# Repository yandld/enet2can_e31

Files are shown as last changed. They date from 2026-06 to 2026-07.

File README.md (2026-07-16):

# NXP Application Code Hub
[](https://www.nxp.com)

## MCXE31B Ethernet-to-Six-CAN FD Bridge
[中文说明](README.zh-CN.md)

This project implements an Ethernet-to-six-CAN FD bridge based on the NXP
MCXE31B. A Linux host loads the `eth2can.ko` driver and sees six standard
SocketCAN interfaces, `eth2can0` through `eth2can5`. Existing SocketCAN tools
and applications can then send and receive CAN FD frames through the MCXE31B
gateway.

The basic architecture is outlined below:

MCXE31B Ethernet-to-six-CAN FD bridge system overview

* **Linux SocketCAN driver:** `eth2can.ko` binds to one Ethernet interface,
  exchanges raw E2CF Layer-2 frames with the gateway, and exposes six CAN FD
  channels as SocketCAN devices.
* **MCXE31B gateway firmware:** The bare-metal firmware receives E2CF Ethernet
  frames, forwards CAN FD traffic through FlexCAN0..FlexCAN5, reports status,
  and supervises the heartbeat between Linux and the gateway.
* **Customer validation tool:** `canperf` provides latency and bidirectional
  maximum sustainable bandwidth checks for the default six-channel harness.

#### Boards: MCXE31B gateway board
#### Categories: Tools
#### Peripherals: CAN FD, Ethernet
#### Toolchains: MDK, GCC

## Table of Contents
1. [Software](#step1)
2. [Hardware](#step2)
3. [Setup](#step3)
4. [Results](#step4)
5. [FAQs](#step5)
6. [Support](#step6)
7. [Release Notes](#step7)

## 1. Software

This repository contains the MCXE31B firmware, Linux driver, validation tool,
and design notes required to bring up the bridge.

Project classification and description:

| Project | Path | Description |
|---|---|---|
| MCXE31B firmware | `source/`, `board/` | Bare-metal bridge firmware using ENET_QOS raw Layer-2 Ethernet and FlexCAN0..FlexCAN5 |
| Linux driver | `linux/` | Out-of-tree SocketCAN driver, installer script, and driver tests |
| canperf | `linux/can_testcase/` | Customer latency and bidirectional bandwidth validation tool |
| Design notes | `docs/*.md` | E2CF protocol, Linux driver, firmware, and EQOS TX design documentation |

Default bridge configuration:

| Item | Default |
|---|---|
| Host API | SocketCAN devices `eth2can0` through `eth2can5` |
| Ethernet transport | Raw Layer-2 E2CF, EtherType `0x88B5` |
| Deployment VLAN | VID `100`; untagged frames are allowed during bring-up |
| CAN FD nominal bitrate | 1 Mbit/s |
| CAN FD data bitrate | 5 Mbit/s |
| CAN FD BRS | Enabled |
| TX window | 16 echo/TXC slots per CAN channel |
| MCU-to-Linux aggregation | Record-count based or 50 us timer |
| Heartbeat supervision | 100 ms period, 500 ms timeout |

### Software Protocol

E2CF is a little-endian raw Ethernet protocol shared by the Linux driver and
the MCXE31B firmware. The frame EtherType is `0x88B5`. The protocol carries
CAN frame data, CAN transmit-completion status, configuration transactions,
events, time mapping, heartbeat, and statistics.

Message types used by this delivery:

| Type | Direction | Purpose |
|---|---|---|
| DATA | Both directions | CAN frames or Linux transmit requests |
| TXC | MCXE31B to Linux | CAN transmit completion and echo-slot release |
| EVT | MCXE31B to Linux | CAN state and error events |
| CFG_REQ / CFG_RSP | Linux to MCXE31B / MCXE31B to Linux | Channel configuration and status transactions |
| TIME | MCXE31B to Linux | Gateway time mapping |
| HB | Both directions | Peer discovery and heartbeat supervision |
| STATS | MCXE31B to Linux | Gateway counters for diagnostics and validation |

E2CF data and management paths between Linux and the MCXE31B gateway

For protocol details, see
[`docs/e2cf-protocol-spec.md`](docs/e2cf-protocol-spec.md).

## 2. Hardware

Use one MCXE31B gateway board, one Linux host connected to the gateway Ethernet
port, and six external CAN FD transceivers.

Default CAN FD harness:

```text
eth2can0 <-> eth2can4
eth2can1 <-> eth2can2
eth2can3 <-> eth2can5
```

Each pair is one independent CAN FD bus. Use 120 ohm termination at both ends,
keep CANH/CANL polarity correct, power the transceivers, and share ground with
the gateway board.

### Pin Table

The table below lists the primary CAN, Ethernet, and debug UART connections
used by this project.

| Function | MCU signal | Package pin | Description |
|---|---|---:|---|
| CAN0 TX/RX | PTA7 / PTA6 | 100 / 102 | CAN0 transceiver TXD/RXD |
| CAN1 TX/RX | PTA11 / PTA12 | 160 / 159 | CAN1 transceiver TXD/RXD |
| CAN2 TX/RX | PTE24 / PTE25 | 157 / 158 | CAN2 transceiver TXD/RXD |
| CAN3 TX/RX | PTC28 / PTC29 | 96 / 99 | CAN3 transceiver TXD/RXD |
| CAN4 TX/RX | PTC30 / PTC31 | 101 / 103 | CAN4 transceiver TXD/RXD |
| CAN5 TX/RX | PTC27 / PTC26 | 93 / 91 | CAN5 transceiver TXD/RXD |
| RMII MDIO/MDC | PTB4 / PTB5 | 48 / 47 | Ethernet PHY management |
| RMII data/control | PTC2, PTD7, PTD12, PTC17, PTC1, PTC0, PTD11 | 50, 51, 54, 65, 61, 62, 55 | Ethernet RMII signals |
| PHY reset | PTC3 | 49 | Ethernet PHY reset GPIO |
| Debug UART RX/TX | PTE3 / PTE14 | 27 / 26 | Debug console |

Status LED behavior:

| LED | State | Meaning |
|---|---|---|
| SYS | About 1 Hz blinking | Firmware superloop is running |
| NET | Solid on | Ethernet/E2CF link is ready |
| CAN | Blinking | CAN RX/TX traffic is active |
| CAN | Solid on | At least one active CAN bus is error-passive or bus-off |

## 3. Setup

Before getting started, prepare a Linux host with SocketCAN support, matching
kernel headers or a matching kernel build tree, and common tools such as
`make`, `gcc`, `kmod`, `iproute2`, and `can-utils`.

### 3.1 Step 1

Program or confirm the MCXE31B gateway firmware. If the board is already
programmed, power it up. To build the firmware yourself, open
`e2cf_mcxe31.uvprojx` in Keil MDK, build the MCXE31B target, and program the
board with your normal MCXE31B/SWD flow.

### 3.2 Step 2

Connect the Linux host to the MCXE31B Ethernet port. Connect the default CAN FD
harness:

```text
eth2can0 <-> eth2can4
eth2can1 <-> eth2can2
eth2can3 <-> eth2can5
```

### 3.3 Step 3

Build and load the Linux driver from the repository root:

```bash
$ sh linux/scripts/install_driver.sh
```

Common variants:

```bash
$ sh linux/scripts/install_driver.sh --ifname eth1 --vid 100
$ KDIR=/path/to/kernel/build sh linux/scripts/install_driver.sh --ifname end0
$ sh linux/scripts/install_driver.sh --dry-run
$ sh linux/scripts/install_driver.sh --require-gateway
```

The installer builds `eth2can.ko`, loads it for the current boot, waits for the
gateway heartbeat, and configures `eth2can0..5` for CAN FD 1M/5M. It does not
install DKMS, systemd units, or persistent autoload configuration.

### 3.4 Step 4

Confirm the SocketCAN devices:

```bash
$ ip -details link show type can
```

Six interfaces, `eth2can0` through `eth2can5`, should be present.

### 3.5 Step 5

Run a basic CAN FD transmit check:

```bash
$ candump eth2can4 &
$ cansend eth2can0 123##3001122334455667788
```

If `eth2can4` receives the frame, the Linux driver, Ethernet transport,
MCXE31B firmware, and at least one physical CAN FD bus are working.

### 3.6 Step 6

Build and run the customer validation tool:

```bash
$ cd linux/can_testcase
$ make
$ ./canperf latency --count 10000
$ ./canperf bandwidth
```

## 4. Results

The expected first-level result is that all six SocketCAN devices are created,
the default harness passes basic `candump` / `cansend` traffic, and `canperf`
prints final `RESULT` and `EVIDENCE` lines.

Example result lines:

```bash
RESULT latency: PASS, zero_loss=yes, ...
EVIDENCE latency: ..., counters=clean
RESULT bandwidth: PASS, zero_loss=yes, MSR=... fps/pair, ...
EVIDENCE bandwidth: ..., counters=clean
```

For acceptance, use the final `RESULT` line as the customer conclusion. `PASS`
means zero-loss for that run. Latency reports p50, p99, and p99.9. Bandwidth
reports MSR, the maximum sustainable rate. `counters=clean` means relevant
driver and gateway loss, overflow, reject, and send-failure counters did not
increase during the confirmation round.

This repository does not define fixed p99 or MSR pass/fail limits. Thresholds
must be agreed for the target harness, host, and system load.

## 5. FAQs

* Why does the Linux host see six `eth2canN` devices instead of one raw
  Ethernet device?

  The Linux driver presents the gateway as standard SocketCAN interfaces so
  existing CAN applications can run without a custom user-space API.

* Does the MCXE31B firmware use TCP/IP or lwIP?

  No. The firmware uses ENET_QOS raw Layer-2 Ethernet and the E2CF protocol.

* Are fixed p99 latency or MSR bandwidth limits defined by this repository?

  No. The tools report measured latency, MSR, and clean/dirty counters. Final
  limits depend on the harness, Linux host, and system load.

* Is this repository an open-source release?

  No. It is not published under an open-source license in its current form.
  See the distribution notice below.

## 6. Support

#### Project Metadata
<!----- Boards ----->


<!----- Categories ----->


<!----- Peripherals ----->



<!----- Toolchains ----->



Questions regarding the content or correctness of this project can be entered
as Issues within this GitHub repository.

> **Warning**: For general technical questions about NXP microcontrollers,
> use the [NXP Community Forum](https://community.nxp.com/).






Distribution notice: this repository is not published under an open-source
license in its current form. Copying, redistribution, product use, or
publication outside the authorized project scope requires written permission
from the repository owner. Preserve all SPDX notices in source files.

## 7. Release Notes

| Version | Description / Update | Date |
|:---:|---|---:|
| 1.0 | Initial release for MCXE31B Ethernet-to-six-CAN FD bridge | July 4<sup>th</sup> 2026 |

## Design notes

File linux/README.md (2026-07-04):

# eth2can Linux Driver Installation and Test

[中文说明](README.zh-CN.md)

`eth2can.ko` exposes the six MCXE31B CAN FD channels as standard SocketCAN
devices, `eth2can0` through `eth2can5`. Normal users only need to install the
driver, confirm the Ethernet/E2CF heartbeat, run a basic CAN transmit check,
and run `canperf` when acceptance evidence is required.

Default CAN FD configuration:

```text
bitrate  1000000
dbitrate 5000000
fd       on
```

## Requirements

- A Linux distribution or BSP kernel with SocketCAN enabled:
  `CONFIG_CAN`, `CONFIG_CAN_RAW`, and `CONFIG_CAN_DEV`
- A kernel build tree matching the running `uname -r`, usually
  `/lib/modules/$(uname -r)/build`
- Common tools: `make`, `gcc`, `kmod`, `iproute2`, and `can-utils`

Raspberry Pi, Ubuntu/Debian, RK/i.MX vendor Linux, and similar systems use the
same installer. If the vendor BSP does not provide standard headers, pass the
matching kernel build directory through `KDIR=`.

## One-command installation

Run from the repository root:

```sh
sh linux/scripts/install_driver.sh
```

The script builds and loads `eth2can.ko`, waits for the MCXE31B heartbeat, and
configures `eth2can0..5` for CAN FD 1M/5M. It does not install DKMS, write
systemd units, or configure persistent module autoload.

Common options:

```sh
sh linux/scripts/install_driver.sh --ifname eth1
sh linux/scripts/install_driver.sh --ifname eth1 --vid 100
KDIR=/path/to/kernel/build sh linux/scripts/install_driver.sh --ifname end0
sh linux/scripts/install_driver.sh --dry-run
sh linux/scripts/install_driver.sh --no-load
sh linux/scripts/install_driver.sh --require-gateway
```

Explicit bitrate override:

```sh
sh linux/scripts/install_driver.sh --bitrate 1000000 --dbitrate 5000000
```

## Manual commands

When debugging installer failures, load and configure the driver manually:

```sh
sudo insmod linux/eth2can.ko ifname=eth0
sudo ip link set eth0 up
sudo ip link set eth2can0 type can bitrate 1000000 dbitrate 5000000 fd on
sudo ip link set eth2can0 up
```

Before basic traffic tests, check that each CAN FD bus has 120 ohm termination
at both ends, correct CANH/CANL polarity, powered transceivers, and common
ground.

Default harness:

```text
eth2can0 <-> eth2can4
eth2can1 <-> eth2can2
eth2can3 <-> eth2can5
```

Basic transmit check:

```sh
candump eth2can4 &
cansend eth2can0 123##3001122334455667788
```

## Performance test entry point

```sh
cd linux/can_testcase
make
./canperf latency --count 10000
./canperf bandwidth
```

For acceptance, use the final `RESULT` line. `latency` reports end-to-end
p50, p99, and p99.9. `bandwidth` reports bidirectional MSR, the maximum
sustainable rate. `zero_loss=yes` means no application-level loss for the run.
`counters=clean` means readable driver and gateway counters did not increase
for loss, overflow, reject, or send-failure conditions. This repository does
not define fixed p99 or MSR limits.

## Troubleshooting

| Symptom | Checks |
|---|---|
| `/lib/modules/$(uname -r)/build` is missing | Install headers matching the running kernel, or pass `KDIR=` |
| `vermagic` mismatch | Rebuild `eth2can.ko` on the target kernel |
| No `eth2can0..5` devices | Check `dmesg` for insmod errors and verify SocketCAN kernel config |
| `gateway heartbeat was not observed` | Check cable, selected `--ifname`, MCXE31B firmware, switch path, and VLAN |
| `ip link set eth2canN ...` times out | Heartbeat is not established or the gateway did not answer CFG |
| CAN frame is not received | Check default harness, termination, transceiver power, common ground, CANH/CANL polarity, and bitrate |

LED hints:

| LED | State | Direction |
|---|---|---|
| SYS | About 1 Hz blinking | Firmware superloop is running |
| SYS | Not blinking | Check firmware image, power, and reset first |
| NET | Off | PHY link down; check cable, switch, and host interface state |
| NET | Blinking | PHY link up but E2CF peer heartbeat is not ready |
| NET | Solid on | Ethernet/E2CF link is ready |
| CAN | Blinking | CAN RX/TX traffic is active |
| CAN | Solid on | At least one active CAN channel is error-passive or bus-off |

Heartbeat capture:

```sh
sudo tcpdump -eni eth0 'ether proto 0x88b5 or (vlan and ether proto 0x88b5)'
```

Expected traffic is an EtherType `0x88B5` heartbeat every 100 ms. If tcpdump
sees traffic but the driver never reports `gateway alive`, save the packet
capture and `dmesg` for support.

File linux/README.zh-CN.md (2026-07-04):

# eth2can Linux 驱动安装与测试

[English](README.md)

`eth2can.ko` 将 MCXE31B 的六路 CAN FD 暴露为标准 SocketCAN 设备：
`eth2can0` 到 `eth2can5`。普通用户默认只需要安装驱动、确认
Ethernet/E2CF heartbeat、运行基础 CAN 收发检查，并在需要验收证据时运行
`canperf`。

默认 CAN FD 配置：

```text
bitrate  1000000
dbitrate 5000000
fd       on
```

## 环境要求

- Linux 发行版或 BSP 内核启用 SocketCAN：
  `CONFIG_CAN`、`CONFIG_CAN_RAW`、`CONFIG_CAN_DEV`
- 与当前 `uname -r` 匹配的 kernel build tree，通常为
  `/lib/modules/$(uname -r)/build`
- 常用工具：`make`、`gcc`、`kmod`、`iproute2`、`can-utils`

Raspberry Pi、Ubuntu/Debian、RK/i.MX vendor Linux 等系统都使用同一个安装
脚本。如果 vendor BSP 没有标准 headers，请通过 `KDIR=` 指向匹配的内核构建
目录。

## 一键安装

在仓库根目录运行：

```sh
sh linux/scripts/install_driver.sh
```

脚本会构建并加载 `eth2can.ko`，等待 MCXE31B heartbeat，然后将
`eth2can0..5` 配置为 CAN FD 1M/5M。脚本不会安装 DKMS，不会写 systemd
unit，也不会配置跨重启自动加载。

常用选项：

```sh
sh linux/scripts/install_driver.sh --ifname eth1
sh linux/scripts/install_driver.sh --ifname eth1 --vid 100
KDIR=/path/to/kernel/build sh linux/scripts/install_driver.sh --ifname end0
sh linux/scripts/install_driver.sh --dry-run
sh linux/scripts/install_driver.sh --no-load
sh linux/scripts/install_driver.sh --require-gateway
```

显式覆盖速率：

```sh
sh linux/scripts/install_driver.sh --bitrate 1000000 --dbitrate 5000000
```

## 手动命令

安装脚本失败排查时，可手动加载和配置驱动：

```sh
sudo insmod linux/eth2can.ko ifname=eth0
sudo ip link set eth0 up
sudo ip link set eth2can0 type can bitrate 1000000 dbitrate 5000000 fd on
sudo ip link set eth2can0 up
```

基础流量测试前，确认每条 CAN FD 总线两端各有 120 ohm 终端，CANH/CANL
极性正确，收发器供电正常并共地。

默认线束：

```text
eth2can0 <-> eth2can4
eth2can1 <-> eth2can2
eth2can3 <-> eth2can5
```

基础收发检查：

```sh
candump eth2can4 &
cansend eth2can0 123##3001122334455667788
```

## 性能测试入口

```sh
cd linux/can_testcase
make
./canperf latency --count 10000
./canperf bandwidth
```

验收时先看最终 `RESULT` 行。`latency` 报告端到端 p50、p99 和 p99.9；
`bandwidth` 报告双向 MSR，即 maximum sustainable rate。`zero_loss=yes`
表示本次运行应用层无丢帧。`counters=clean` 表示可读的驱动和网关计数器
没有出现丢帧、溢出、拒绝或发送失败增量。本仓库不定义固定 p99 或 MSR 阈值。

## 故障排查

| 现象 | 检查项 |
|---|---|
| 找不到 `/lib/modules/$(uname -r)/build` | 安装与当前内核匹配的 headers，或传入 `KDIR=` |
| `vermagic` 不匹配 | 在目标内核上重新构建 `eth2can.ko` |
| 没有 `eth2can0..5` 设备 | 查看 `dmesg` 中的 insmod 错误，并确认 SocketCAN 内核配置 |
| `gateway heartbeat was not observed` | 检查网线、`--ifname`、MCXE31B 固件、交换路径和 VLAN |
| `ip link set eth2canN ...` 超时 | heartbeat 未建立，或网关没有响应 CFG |
| CAN 收不到帧 | 检查默认线束、终端、收发器供电、共地、CANH/CANL 极性和速率 |

LED 辅助判断：

| LED | 状态 | 检查方向 |
|---|---|---|
| SYS | 约 1 Hz 闪烁 | 固件主循环正常运行 |
| SYS | 不闪烁 | 先检查固件镜像、电源和复位 |
| NET | 熄灭 | PHY link down；检查网线、交换机和主机网口状态 |
| NET | 闪烁 | PHY link up，但 E2CF peer heartbeat 尚未 ready |
| NET | 常亮 | Ethernet/E2CF 链路 ready |
| CAN | 闪烁 | CAN RX/TX 流量正在通过 |
| CAN | 常亮 | 至少一个 active CAN 通道 error-passive 或 bus-off |

抓取 heartbeat：

```sh
sudo tcpdump -eni eth0 'ether proto 0x88b5 or (vlan and ether proto 0x88b5)'
```

期望每 100 ms 看到一次 EtherType `0x88B5` heartbeat。如果 tcpdump 能看到流量，
但驱动始终没有 `gateway alive`，请保存抓包和 `dmesg` 给支持团队。

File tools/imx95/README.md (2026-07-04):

# i.MX95 Maintainer Bench Notes

[中文说明](README.zh-CN.md)

This directory contains maintainer-only scripts for an internal i.MX95/RTE
bench. They are used to build a vendor kernel, deploy the driver, copy test
tools, and maintain the boot partition during integration work.

These scripts are not the customer bring-up entry point. For normal Linux
hosts, use:

```sh
sh linux/scripts/install_driver.sh
cd linux/can_testcase && make && ./canperf latency
```

## Default configuration

The bench scripts keep the same customer-facing CAN FD defaults:

```text
bitrate  1000000
dbitrate 5000000
```

`board_setup.sh` loads `eth2can.ko` on the target board, waits for the MCXE31B
heartbeat, and configures `eth2can0..5`.

## When to use

- i.MX95/RTE bench automation
- Vendor kernel and driver integration
- Board preparation before repeated `canperf latency` or `canperf bandwidth`
  runs

Do not use this directory as a generic installation path for Raspberry Pi,
Ubuntu/Debian, RK/i.MX vendor Linux, or other customer systems. Use
`linux/scripts/install_driver.sh` instead.

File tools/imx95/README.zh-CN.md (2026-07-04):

# i.MX95 维护者 Bench 说明

[English](README.md)

本目录包含维护者专用的内部 i.MX95/RTE bench 脚本，用于构建 vendor kernel、
部署驱动、拷贝测试工具，以及在集成工作中维护启动分区。

这些脚本不是客户 bring-up 入口。普通 Linux 主机请使用：

```sh
sh linux/scripts/install_driver.sh
cd linux/can_testcase && make && ./canperf latency
```

## 默认配置

bench 脚本保持与客户侧一致的 CAN FD 默认值：

```text
bitrate  1000000
dbitrate 5000000
```

`board_setup.sh` 会在目标板上加载 `eth2can.ko`，等待 MCXE31B heartbeat，
然后配置 `eth2can0..5`。

## 何时使用

- i.MX95/RTE bench 自动化
- vendor kernel 和驱动集成
- 重复运行 `canperf latency` 或 `canperf bandwidth` 前的板端准备

不要把本目录作为 Raspberry Pi、Ubuntu/Debian、RK/i.MX vendor Linux 或其他
客户系统的通用安装路径。请使用 `linux/scripts/install_driver.sh`。

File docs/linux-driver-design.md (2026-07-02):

# Linux 驱动设计

## 1. 模块和接口

Linux 驱动模块名为 `eth2can`，下层绑定一个以太网接口，默认 `ifname=eth0`。驱动创建 6 个 SocketCAN 设备：`eth2can0` 到 `eth2can5`。每个设备对应 E2CF 通道 0..5。

模块参数：

| 参数 | 默认值 | 说明 |
|---|---|---|
| `ifname` | `eth0` | 承载 E2CF raw L2 帧的以太网接口 |
| `vid` | `-1` | `-1` 表示 bring-up 使用 untagged；部署可设为 `100` |
| `peer` | 空 | 为空时从 MCU HB 自动学习 peer MAC |

客户交付默认 CAN FD 配置为 `bitrate 1000000 dbitrate 5000000 fd on`。

## 2. 数据结构

驱动使用一个全局 `struct e2cf_dev` 管理底层以太网、peer MAC、HB/TIME/STATS 状态和全局序号。每个 CAN 通道使用一个 `struct e2cf_chan`，保存 candev、echo slot、CFG 状态、TXC 统计和 MCU 通道状态缓存。

每通道 echo 窗口深度为 16，与协议 `E2CF_WIN_DEPTH` 和 MCU `sw_txfifo` 深度一致。窗口 slot 号写入 DATA 记录 `tag`，MCU 在 TXC 中原样回显。

## 3. TX 路径：Linux -> MCU -> CAN

`ndo_start_xmit` 对 SocketCAN skb 做合法性检查后，分配一个空闲 echo slot：

1. `can_dropped_invalid_skb()` 过滤非法 CAN skb。
2. `find_first_zero_bit(echo_busy)` 获取 echo slot。
3. 窗口满时 `netif_stop_queue()` 并返回 `NETDEV_TX_BUSY`。
4. 构造 E2CF DATA 帧，写入 `chan`、`tag`、`can_id`、`len`、`flags` 和 payload。
5. 调用 `dev_queue_xmit()` 发送到底层以太网接口。
6. 调用 `can_put_echo_skb()` 保存 echo skb，等待 TXC 完成语义。

当前驱动每个 CAN skb 生成一个 E2CF DATA 以太帧。MCU 侧按每通道 FIFO 顺序装填单 active TX MB，CAN 发送完成后返回 TXC。

## 4. RX 路径：MCU -> Linux

驱动通过 `dev_add_pack()` 注册 EtherType `0x88B5` 的 `packet_type` 回调，在 softirq 上下文解析 E2CF 帧。

处理规则：

- DATA：逐条构造 `can_skb` 或 `canfd_skb`，注入对应 `eth2canN`。
- TXC：按 `chan/tag` 查找 echo slot，成功时 `can_get_echo_skb()`，错误时释放 echo skb 并统计 TX error。
- EVT：更新 CAN error state，并在需要时注入 CAN error frame。
- CFG_RSP：唤醒等待中的配置事务。
- TIME：更新网关时间映射，用于硬件时间戳还原。
- HB：刷新 peer 存活状态，检测 MCU 重启并触发恢复。
- STATS：缓存 MCU 统计，供 `ethtool -S` 和 debugfs 查询。

## 5. 配置和恢复

`ndo_open` 流程：

1. `open_candev()`。
2. 发送 SET_BITRATE，包含 Linux CAN bit timing 和 mode flags。
3. 发送 START。
4. `netif_start_queue()`。

`ndo_stop` 流程：

1. 发送 STOP。
2. 清理 echo slot。
3. `close_candev()`。

当 HB 超时或 MCU uptime 回退时，驱动进入恢复流程：停止队列，清理 stale echo slot，重新执行打开通道时的 CFG 序列，然后恢复队列。TXC 超时兜底为 1 s，用于释放因以太帧丢失或异常路径遗留的 echo slot。

## 6. 统计接口

每个 `eth2canN` 支持 `ethtool -S`。统计名前缀：

- `drv_`：驱动本通道计数。
- `drvg_`：驱动全局计数。
- `gw_`：MCU 本通道 STATS/EVT 缓存。
- `gwg_`：MCU 全局 STATS 缓存。

debugfs 路径：

```text
/sys/kernel/debug/eth2can/stats
/sys/kernel/debug/eth2can/clear_stats
```

`clear_stats` 可写 `all` 或 `0..5`。该操作只清计数器，不改变通道配置或运行状态。

## 7. 测试和客户输出

客户测试入口为：

```sh
cd linux/can_testcase
make
./canperf latency --count 10000
./canperf bandwidth
```

`latency` 输出端到端 p50/p99/p99.9 和分段延迟。`bandwidth` 先搜索候选速率，再执行 final confirmation。客户只看最终 `RESULT` 和 `EVIDENCE` 行：

```text
RESULT latency: PASS, zero_loss=yes, ...
RESULT bandwidth: PASS, zero_loss=yes, MSR=... fps/pair, ...
EVIDENCE ... counters=clean
```

`counters=clean` 表示驱动和网关关键丢包、溢出、拒绝计数器在本次确认轮未增长。

## 8. 验收要点

- 6 个 `eth2canN` 设备可创建并可配置为 CAN FD 1M/5M。
- 默认线束 `0<->4`、`1<->2`、`3<->5` 下，`canperf latency` 输出 `RESULT latency: PASS`。
- `canperf bandwidth` 输出 `RESULT bandwidth: PASS` 和 `MSR = ... fps/pair DELIVERED`。
- debugfs 可读时，最终 `EVIDENCE` 行应为 `counters=clean`。
- 出现 `counters=dirty` 时，以 `seq_lost`、`rx_ovf`、`rej`、`starv`、`sfail`、`emac_rxdrop` 的增量定位问题。

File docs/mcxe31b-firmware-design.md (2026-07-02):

# MCXE31B 固件设计

## 1. 固件结构

固件为裸机结构，不使用 RTOS 和 lwIP。数据面由 CAN 和 EMAC 中断处理；主循环只执行非硬实时维护：

- E2CF 聚合超时 flush。
- HB、EVT、TIME、STATS 周期发送。
- CAN error polling 和 stuck-TX watchdog。
- PHY link polling。
- 状态 LED 刷新。
- 延迟日志 UART drain 和调试命令。

启动顺序：

```text
BOARD_InitHardware
status_led_init
gw_time_init
dbg_log_init
SysTick_Config
eth_raw_init
can_hw_init
e2cf_core_init
main superloop
```

## 2. 默认配置

交付默认配置：

| 项 | 值 |
|---|---|
| CAN nominal bitrate | 1 Mbit/s |
| CAN FD data bitrate | 5 Mbit/s |
| CAN FD | enabled |
| BRS | enabled |
| active channels | 0..5 |
| TX window / sw FIFO | 16 per channel |
| MCU->Linux aggregation | 50 us |

FlexCAN PE clock 固定使用 AIPS_PLAT_CLK 80 MHz。8 Mbit/s data phase 是设备能力上限，可作为显式 override；交付默认不使用 8 Mbit/s。

## 3. 中断优先级

| 中断 | NVIC priority | 说明 |
|---|---:|---|
| FlexCAN0..5 MB IRQ | 1 | CAN RX 和 TX complete |
| EMAC RX/TX IRQ | 1 | E2CF raw L2 收发 |
| SysTick | 3 | 1 ms tick 和 DWT wrap 跟踪 |

CAN 和 EMAC 同优先级，互不抢占。该设计让 CAN RX、TXC 流控释放和 EMAC RX 在同一数据面优先级内排队，避免单侧长期压制另一侧。

## 4. 状态 LED

三颗状态灯为 active-low GPIO，由 `status_led_poll()` 在主循环中刷新，内部 20 ms 节流，不进入数据面中断路径。

| LED | GPIO | 状态语义 |
|---|---|---|
| SYS | PTC16 | 约 1 Hz 闪烁表示主循环运行；fault/fatal path 常亮 |
| NET | PTB22 | 熄灭=PHY down；闪烁=PHY up 但 E2CF peer 未 ready；常亮=E2CF ready |
| CAN | PTC14 | 熄灭=无 CAN 流量；闪烁=CAN RX/TX 活动；常亮=任一 active/running CAN error-passive 或 bus-off |

## 5. FlexCAN 资源分配

所有 6 个 FlexCAN 实例使用统一的 MB RX bank + 单 active TX MB 结构。

| 通道 | RX MB 数 | TX MB | 说明 |
|---:|---:|---:|---|
| CAN0 | 8 | 1 | 与 CAN1/2 使用同等 RX 深度 |
| CAN1 | 8 | 1 | FD MB 接收 |
| CAN2 | 8 | 1 | FD MB 接收 |
| CAN3 | 4 | 1 | FD MB 接收 |
| CAN4 | 4 | 1 | FD MB 接收 |
| CAN5 | 4 | 1 | FD MB 接收 |

CAN0 当前同样使用 MB RX bank，不启用 eFIFO/eDMA。CAN1..5 在 CAN FD 模式下没有可用于 FD RX 的 FIFO DMA 路径。统一 MB 路径使六路行为一致，便于时序和丢帧判据验证。

## 6. CAN RX 路径

FlexCAN MB IRQ 进入统一 `can_irq()`：

1. 读取 pending MB flags。
2. RX 优先，扫描整个 RX MB bank。
3. 对每个 pending MB 先 W1C 清 flag，再读 MB。
4. 使用 FlexCAN 16-bit timestamp 对同一 bank 内帧排序。
5. 转换成 E2CF DATA 记录，交给 `e2cf_core_can_rx()` 聚合。
6. 再处理 TX complete。

RX MB bank 使用 accept-all 配置。精细过滤由 Linux/SocketCAN 层承担；固件只负责无损搬运和状态上报。

## 7. CAN TX 路径

Linux->MCU DATA 在 EMAC IRQ 中解析后进入对应通道软件 FIFO。每个通道只允许一个 active TX MB：

1. `can_hw_submit_tx()` 校验通道、FD/BRS/RTR、长度和运行状态。
2. 请求进入 16 深软件 FIFO。
3. 通道空闲时 `chan_tx_kick()` 装填 TX MB。
4. TX complete IRQ 生成 TXC，释放当前帧。
5. 继续装填 FIFO 中下一帧。

单 active TX MB 保证同一通道严格按 Linux DATA 到达顺序上总线。多 MB 并行发送可能被 CAN ID 仲裁顺序影响，不用于当前设计。

## 8. EMAC raw L2 路径

固件直接使用 ENET_QOS raw L2，不运行 IP 栈。RX descriptor 和 TX descriptor 由 SDK ENET_QOS 驱动管理，E2CF frame 在中断上下文直接解析或提交。

当前环深：

| 资源 | 数量 | 说明 |
|---|---:|---|
| EQOS RX BD | 16 | 吸收下行 burst |
| EQOS RX buffers | 32 | 每个 buffer 可容纳完整以太帧 |
| EQOS TX BD | 64 | 降低 wrap 边界压力 |
| TX faces | 8 | E2CF sealed frame staging |

TX descriptor 环保留一个空槽，不允许完全填满。TX tail pointer 始终保持在 ring 内地址。

## 9. E2CF core

`e2cf_core` 负责：

- DATA/TXC 聚合和发送。
- CFG_REQ 执行和幂等响应。
- HB peer lock、安全态和恢复。
- TIME/STATS/EVT 发送。
- 以太帧 `seq_lost` / `seq_reorder` 统计。

MCU->Linux DATA/TXC 聚合只由两个条件触发：记录达到上限，或 50 us `T_agg` 到期。聚合不会因为 EQOS TX ring 暂时空闲而提前 flush。

## 10. 时间戳

网关时间为 DWT cycle counter 扩展出的 64 位单调纳秒时钟。SysTick 每 1 ms 跟踪 DWT wrap。

时间戳用途：

- CAN RX：进入 RX ISR 并读取 MB 后采样网关时间。
- TXC：TX complete IRQ 中采样网关时间。
- DATA trailer：E2CF DATA 以太帧提交给 EQOS TX 时采样。
- TIME：1 Hz 发送完整网关时间给 Linux 做时间映射。

FlexCAN 16-bit MB timestamp 只用于同一 RX bank 内排序，不作为对外协议时间戳。

## 11. 安全态和错误处理

MCU 500 ms 未收到 Linux HB 后进入安全态：

- 停止装填新的 CAN TX MB。
- CAN RX 继续被硬件接收，但不上送 DATA。
- HB 状态变为 FAULT。
- 收到 Linux HB 后清除安全态，等待 Linux 重新配置通道。

CAN bus-off、RX overrun、TX queue overflow、stuck TX watchdog 等通过 EVT、TXC status 和 STATS 上报。Linux 驱动按 SocketCAN 语义恢复通道。

## 12. 验收项

- 上电后 6 路 FlexCAN PE clock 为 80 MHz。
- 默认 autostart 配置为 1M/5M CAN FD BRS。
- `eth2can0..5` 能通过 CFG STOP/SET_BITRATE/START 配置。
- 默认三组线束 `0<->4`、`1<->2`、`3<->5` 能完成 `canperf latency --count 10000`。
- `canperf bandwidth` final confirmation 输出 `RESULT bandwidth: PASS`。
- debugfs 可读时，最终 `EVIDENCE` 为 `counters=clean`。

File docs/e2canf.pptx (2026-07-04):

## Ethernet to Multi-CANFD Bridge Expander in Robotics

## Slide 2

Ethernet to Multi-CANFD Bridge for Robotics

Key Features
- 6 × CANFD ports bridged to Ethernet on one cable
- Deeply customized Linux SocketCAN using raw socket in Linux Kernel Mode, verified on NXP i.MX95 MPU
- MCXE31B Cortex-M7F @160 MHz, bare-metal SW
- Ethernet layer2 MAC to CANFD on MCXE31B, no LWIP Stack running
- CANFD 1Mbps arb / 5-8 Mbps with 64Bytes Payload per frame
- CAN data loop back(MPU->MCU->MPU) latency < 1ms with 99% statics, max. 1.5mS

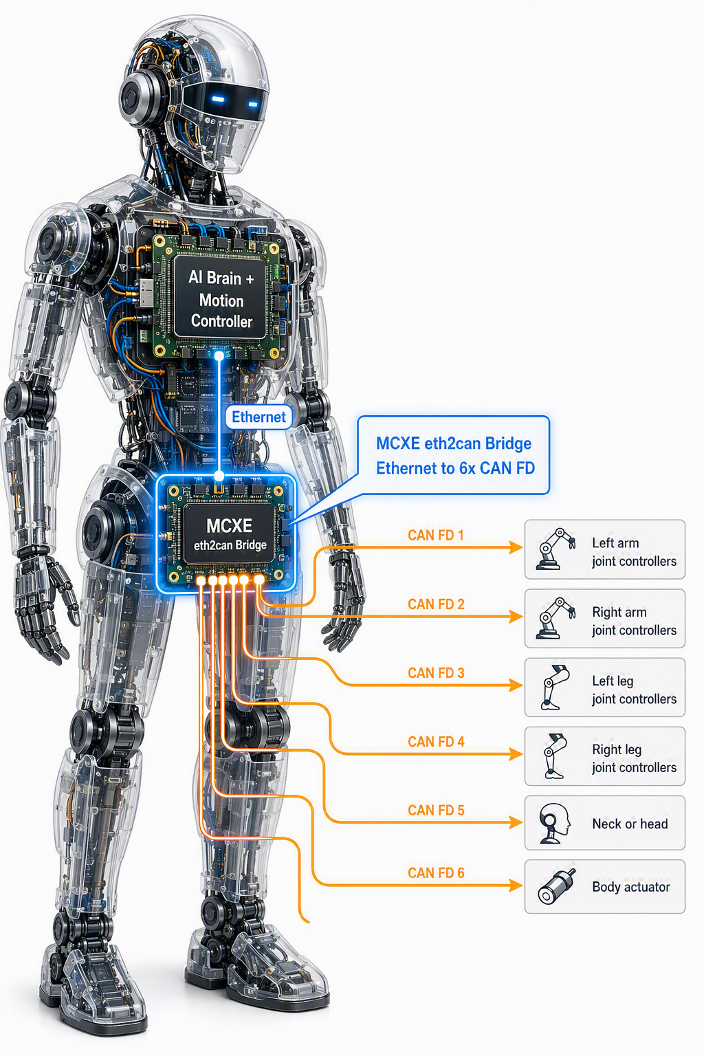
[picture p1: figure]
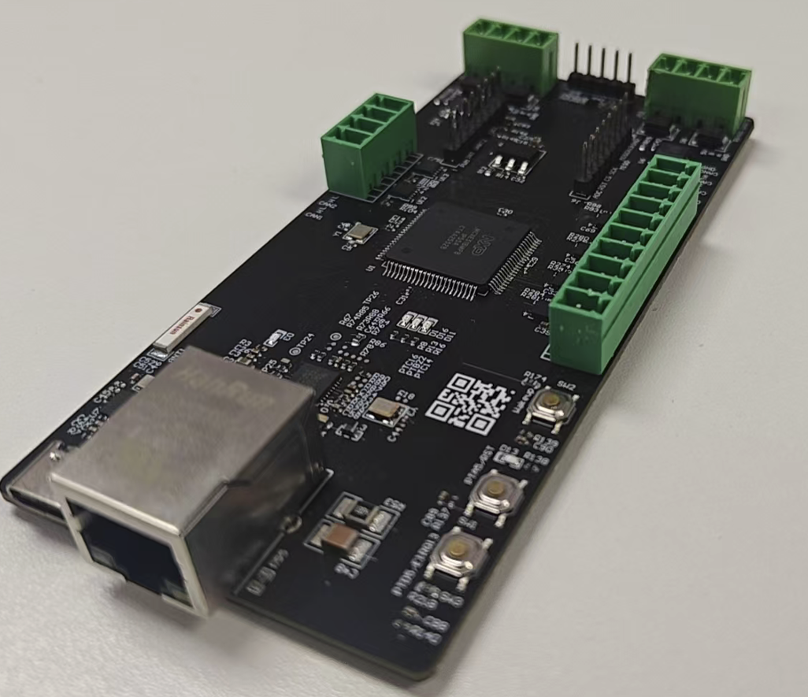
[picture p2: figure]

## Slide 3

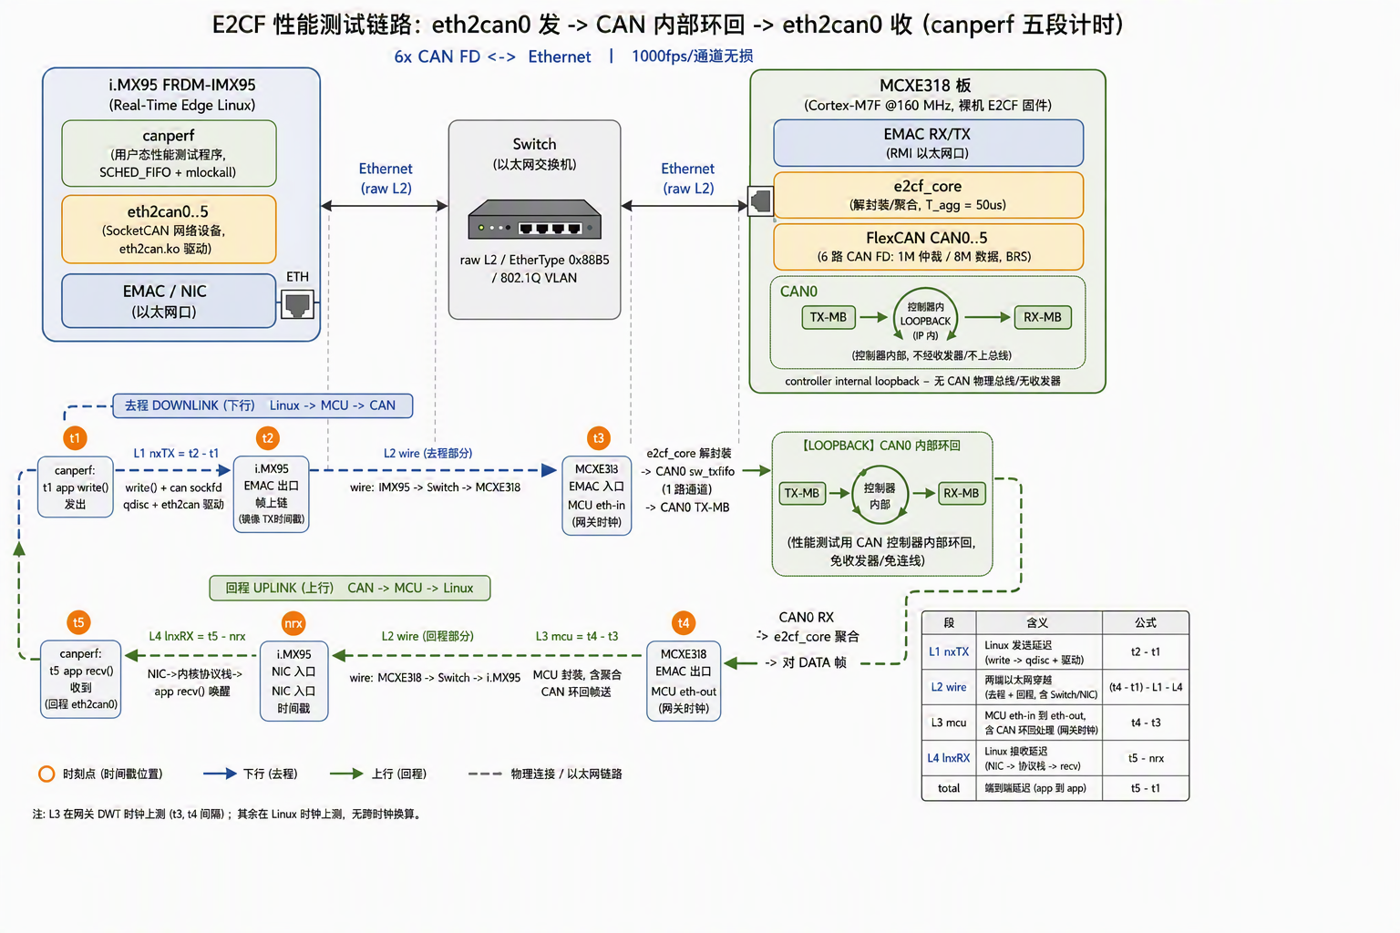
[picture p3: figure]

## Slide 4

Latency test

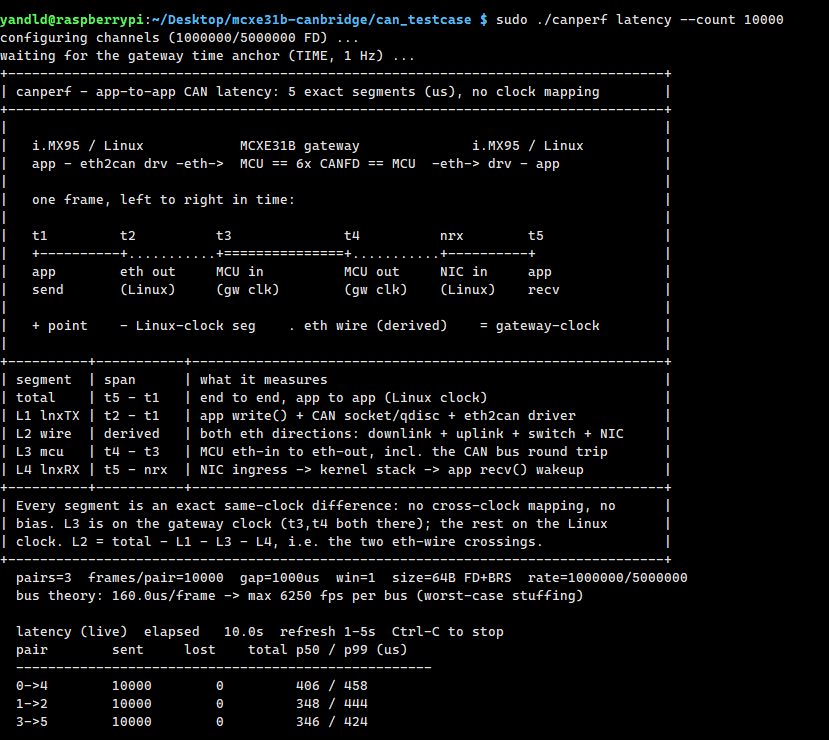
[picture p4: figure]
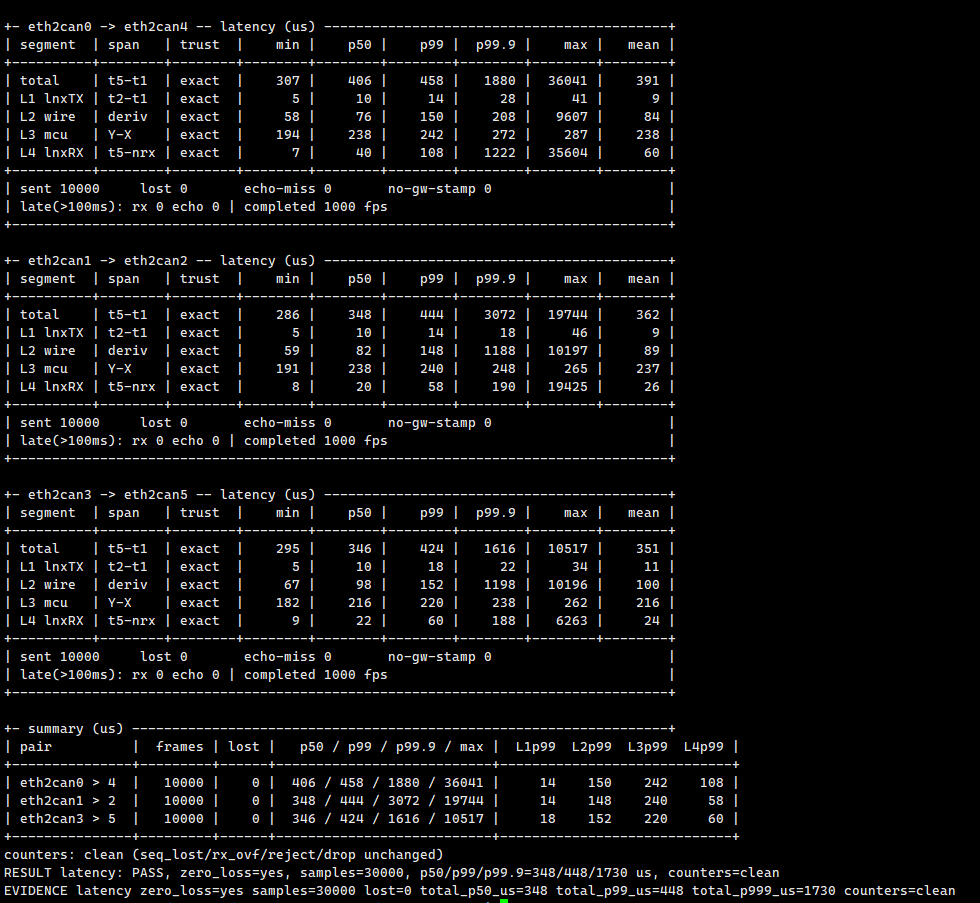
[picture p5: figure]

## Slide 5

Stress test

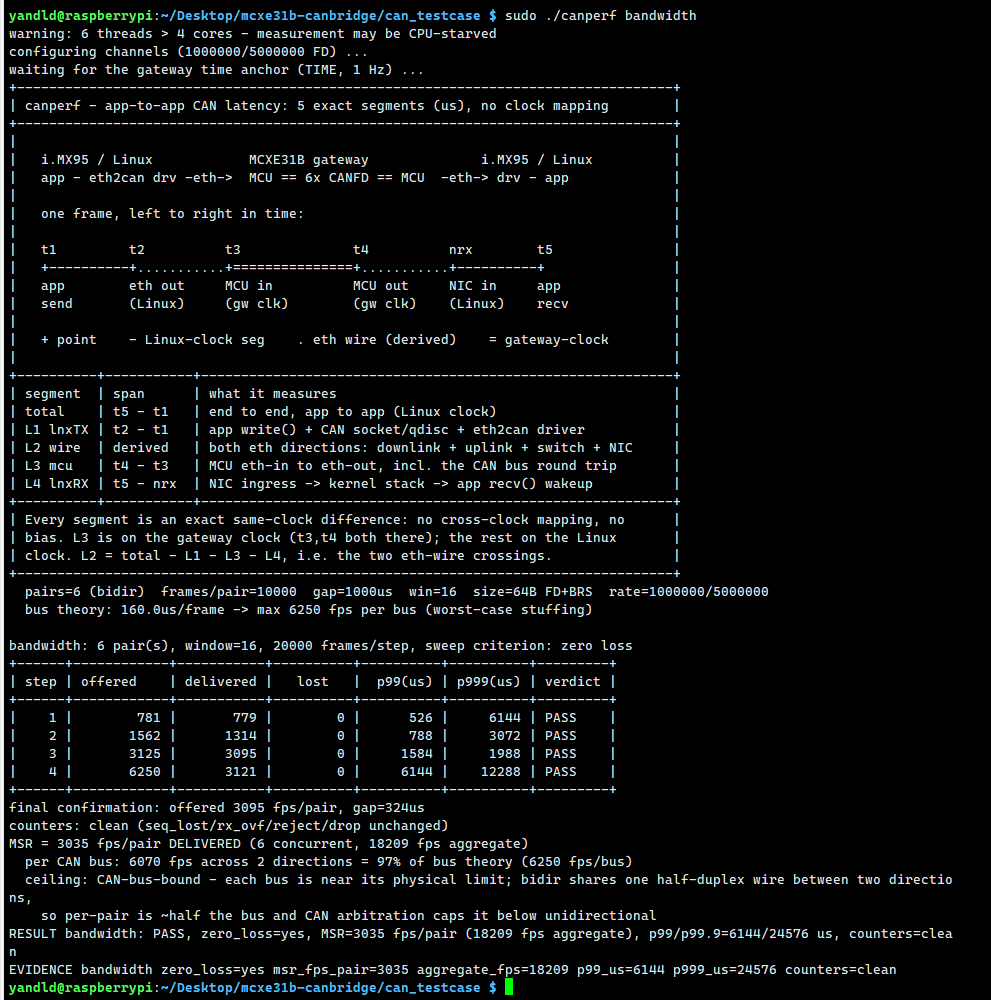
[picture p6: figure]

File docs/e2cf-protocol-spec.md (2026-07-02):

# E2CF 协议规范

## 1. 基本约定

E2CF 是 MCXE31B 网关与 Linux `eth2can` 驱动之间的二层以太网协议。Linux 对外暴露 6 个 SocketCAN 设备：`eth2can0` 到 `eth2can5`。交付默认速率为 CAN FD `bitrate 1000000` / `dbitrate 5000000`，BRS 打开。

协议使用 EtherType `0x88B5`。部署默认使用 802.1Q VLAN，VID 为 `100`；bring-up 阶段允许不带 VLAN 的帧。DATA、TXC、EVT、TIME、HB 使用 PCP 6；CFG_REQ、CFG_RSP、STATS 使用 PCP 2。

所有多字节字段为 little-endian。公共头和记录结构按 4 字节对齐，DATA payload 补齐到 4 字节边界。通道号 `chan` 为 0..5，对应 Linux 设备 `eth2canN` 和 MCU FlexCAN 实例 N。

## 2. 以太帧格式

带 VLAN 的帧格式：

```text
DA(6) | SA(6) | TPID=0x8100(2) | TCI(2) | EtherType=0x88B5(2) | E2CF payload
```

公共头固定 8 字节：

| 偏移 | 字段 | 类型 | 说明 |
|---:|---|---|---|
| 0 | `ver_type` | u8 | 高 4 bit 为版本，当前为 1；低 4 bit 为消息类型 |
| 1 | `count` | u8 | 本帧记录数，非记录类消息固定为 1 |
| 2 | `seq` | u16 | 每端发送方向独立递增，用于丢包/乱序统计 |
| 4 | `ts_base` | u32 | 发送端网关时钟低 32 位纳秒基准 |

消息类型：

| 值 | 类型 | 方向 | 用途 |
|---:|---|---|---|
| 0 | DATA | 双向 | CAN 帧数据或发送请求 |
| 1 | TXC | MCU -> Linux | CAN 发送完成确认 |
| 2 | EVT | MCU -> Linux | CAN 状态和错误事件 |
| 3 | CFG_REQ | Linux -> MCU | 配置请求 |
| 4 | CFG_RSP | MCU -> Linux | 配置响应 |
| 5 | TIME | MCU -> Linux | 网关完整时间 |
| 6 | HB | 双向 | 心跳和 peer 发现 |
| 7 | STATS | MCU -> Linux | 网关统计推送 |

## 3. DATA

DATA 记录头固定 8 字节，后接 `ceil4(len)` 字节 payload：

| 偏移 | 字段 | 类型 | 说明 |
|---:|---|---|---|
| 0 | `can_id` | u32 | SocketCAN `can_id` 语义，含 EFF/RTR 标志 |
| 4 | `len` | u8 | 实际 payload 长度，0..64 |
| 5 | `flags` | u8 | bit0=BRS，bit1=ESI，bit2=FDF |
| 6 | `chan` | u8 | 通道号 0..5 |
| 7 | `tag` | u8 | Linux->MCU 为 echo slot；MCU->Linux 为 2 us 单位的 `ts_off` |

约束：

- FDF=0 时 `len <= 8` 且 BRS=0。
- FDF=1 时不允许 RTR。
- BRS=1 只允许用于数据相位速率高于仲裁相位速率的通道。
- Linux->MCU 的 ESI 必须为 0；MCU 接收时忽略该位。
- 非法记录由 MCU 拒绝，并返回 TXC `CTRL_ERROR`，不得静默截断或改写。

MCU->Linux 的 DATA 帧在最后一条记录后追加 4 字节 trailer：网关时钟低 32 位纳秒，表示该以太帧提交给 EQOS TX 的时间。该 trailer 不计入 `count`。

单个 DATA 以太帧最多包含 17 条 64 字节 CAN FD 记录。

## 4. TXC

TXC 是 Linux 侧发送窗口的唯一释放机制。MCU 只有在对应 CAN 帧真正完成发送后才返回 TXC。

TXC 记录 12 字节：

| 偏移 | 字段 | 类型 | 说明 |
|---:|---|---|---|
| 0 | `chan` | u8 | 通道号 |
| 1 | `tag` | u8 | 对应 DATA 请求的 echo slot |
| 2 | `status` | u8 | 发送结果 |
| 3 | `rsv` | u8 | 0 |
| 4 | `ts_off` | u32 | TX complete 相对本 TXC 帧 `ts_base` 的纳秒偏移 |
| 8 | `req_eth_rx_ns` | u32 | 请求帧到达 MCU EMAC 的网关时钟低 32 位纳秒 |

`status` 定义：

| 值 | 名称 | 说明 |
|---:|---|---|
| 0 | OK | 已完成 CAN 发送 |
| 1 | ARB_LOST | one-shot 仲裁失败放弃；当前固件不启用 one-shot |
| 2 | CTRL_ERROR | 控制器错误或非法帧 |
| 3 | CHAN_STOPPED | 通道停止或安全态禁止发送 |
| 4 | QUEUE_OVF | MCU 通道软件队列溢出 |

单个 TXC 以太帧最多包含 32 条记录。

## 5. CFG

CFG_REQ 和 CFG_RSP body 固定 24 字节。`token` 由请求方生成，响应必须回显。MCU 对同一通道的重复 token 保持幂等，重复请求返回缓存响应。

操作：

| op | 名称 | 说明 |
|---:|---|---|
| 1 | SET_BITRATE | 设置仲裁/数据相位 bit timing 和 mode flags |
| 2 | SET_MODE | 仅更新 mode flags |
| 3 | SET_FILTER | 设置过滤器；当前驱动默认接收全部 ID |
| 4 | START | 启动通道 |
| 5 | STOP | 停止通道 |
| 6 | RESET | 复位通道或全局复位 |
| 7 | GET_STATUS | 读取通道状态 |
| 8 | GET_INFO | 读取固件/协议/窗口/时钟能力 |
| 9 | CLEAR_STATS | 清零统计计数器，不改变通道状态 |

`mode_flags`：

| bit | 名称 | 当前行为 |
|---:|---|---|
| 0 | FD | CAN FD 使能 |
| 1 | NONISO | 不支持，返回 ENOTSUP |
| 2 | LISTENONLY | 支持 |
| 3 | LOOPBACK | 支持，主要用于内部 bring-up |
| 4 | ONESHOT | 不支持，返回 ENOTSUP |

CFG 请求 10 ms 未收到匹配响应时重试，最多 3 次。Linux 驱动必须保证 STOP 后再修改 bit timing。

## 6. 心跳、安全态和时间

HB 周期为 100 ms。MCU 在收到 Linux HB 后锁定 peer MAC；500 ms 未收到 peer HB 时进入安全态。安全态下 MCU 停止装填新的 CAN TX MB，CAN RX 不再上送 DATA，等待 Linux 恢复配置。

TIME 消息 1 Hz 发送，body 16 字节：

```text
full_time_ns:u64 | flags:u32 | rsv:u32
```

`flags bit0` 表示网关时间是否与 1588 同步。当前固件使用 DWT 扩展出的 64 位单调时钟，默认不声明 1588 同步。

## 7. STATS 和丢包判据

STATS 由 MCU 1 Hz 推送，包含全局计数和 6 个通道计数。接收端必须按 wire 中的 block length 解析，新增字段只追加在 block 尾部。

关键判据：

- `seq_lost` 为确认丢失帧数。
- `seq_gaps` 只是非连续序号事件数，乱序也会增加，不能单独作为丢包结论。
- `rx_ovf` 表示 CAN RX MB 溢出。
- `data_rx_rejects` 和 TXC 非 OK 状态用于定位下行发送失败原因。

客户验收以 `canperf` 最终 `RESULT` / `EVIDENCE` 行为准：`zero_loss=yes` 且 `counters=clean` 表示本次测试未发现应用层丢帧或驱动/网关关键计数器增长。

## 8. 聚合、排序和流控

MCU->Linux DATA/TXC 聚合使用 50 us `T_agg`。当记录数达到上限或聚合窗口到期时发送。Linux->MCU 当前驱动逐帧提交 DATA，请求仍遵守相同 wire 格式。

每通道 TX 窗口深度为 16。Linux 达到窗口上限时停止该通道队列；收到 TXC 后释放 echo slot 并唤醒队列。MCU 软件 TX FIFO 深度同为 16。

同一通道内 MCU 必须按 DATA 到达顺序发送 CAN 帧，不按 CAN ID 重新排序。跨通道不定义顺序关系。

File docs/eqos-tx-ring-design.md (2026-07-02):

# EQOS TX 环设计

## 1. 设计目标

EQOS TX 路径用于发送 MCU->Linux 的 E2CF DATA、TXC、EVT、TIME、HB 和 STATS 帧。设计目标是：

- TX descriptor 操作短且可在中断上下文调用。
- DMA 读取 payload 时 buffer 内容保持稳定。
- TX ring 不进入满环歧义状态。
- 所有发送失败都能通过计数器暴露。

## 2. 资源配置

当前配置：

| 资源 | 宏 | 数量 | 内存区域 |
|---|---|---:|---|
| TX BD | `E2CF_ETH_TXBD_NUM` | 64 | non-cacheable |
| RX BD | `E2CF_ETH_RXBD_NUM` | 16 | non-cacheable |
| TX faces | `E2CF_ETH_TXFACE_NUM` | 8 | non-cacheable frame staging |

每个 TX face 为一个完整以太帧 buffer。E2CF core 在 face 中完成封包，然后把该 face 交给 EQOS TX descriptor。

## 3. TX face 生命周期

TX face 状态：

```text
free -> open aggregation -> sealed/inflight -> reclaimed -> free
```

规则：

- 聚合中的 face 只由 E2CF core 写入。
- sealed face 交给 EQOS TX 后，直到 descriptor 完成前不得复用。
- `face_reclaim()` 根据 `eth_raw_tx_completed()` 回收 DMA 已完成的 face。
- DATA 和 TXC 使用独立聚合上下文，立即消息使用临时 face。

TX face 数量为 8，可覆盖两个聚合上下文、周期消息和短时 TX ring inflight。

## 4. Descriptor 提交规则

`eth_raw_send()` 在进入 ENET_QOS 发送 API 前短暂关中断，序列化 descriptor 和 tail pointer 访问。

提交前检查：

```c
if ((submitted - reclaimed) >= (TXBD_NUM - 1))
    return kStatus_ENET_QOS_TxFrameBusy;
```

该规则永久保留一个 descriptor 空槽，避免满环状态与空环状态混淆。发送成功后递增 `submitted`；TX complete 事件递增 `reclaimed`。

## 5. Tail pointer 约束

TX tail pointer 必须始终指向 ring 内地址。descriptor index wrap 时，tail pointer 回到 ring base，而不是指向 ring 末尾之后的地址。

固件侧配合规则：

- 不完全填满 TX ring。
- 每次提交只使用一个完整 frame buffer。
- descriptor OWN 位由 ENET_QOS 驱动设置。
- payload buffer 在 face 回收前保持不变。

## 6. 失败处理和统计

`eth_raw_send()` 返回 busy 时：

- `tx_busy` 计数增加。
- 当前 face 保持 sealed 状态，等待后续 reclaim 后重试或由上层统计发送失败。

E2CF core 暴露的关键统计：

| 计数 | 含义 |
|---|---|
| `frames_sent` | 成功提交给 EQOS TX 的 E2CF 帧 |
| `send_fail` | E2CF 发送失败 |
| `face_starved` | 无可用 TX face |
| `emac_tx_busy` | EQOS TX ring 暂时无可用 descriptor |
| `seq_lost` | 接收端确认的以太帧丢失 |

客户验收时，`canperf` final confirmation 的 `EVIDENCE ... counters=clean` 表示本次测试中相关丢包、溢出、拒绝和发送失败计数未增长。

## 7. 验收项

- `E2CF_ETH_TXBD_NUM` 为 64。
- `E2CF_ETH_TXFACE_NUM` 为 8。
- TX ring 提交逻辑保留至少一个空 descriptor。
- TX tail pointer wrap 后仍指向 ring 内。
- 长时间 `canperf bandwidth` final confirmation 不增加 `seq_lost`、`face_starved`、`send_fail`、`emac_tx_busy`。

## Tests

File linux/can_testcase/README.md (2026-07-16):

# canperf Customer Test Tool

[中文说明](README.zh-CN.md)

`canperf` answers two customer acceptance questions for the MCXE31B bridge:

- Latency: `latency`
- Bidirectional maximum sustainable bandwidth: `bandwidth`

The default CAN FD rate is 1M/5M with BRS enabled. The default harness is
`0<->4`, `1<->2`, and `3<->5`.

## Build

Native build on the target Linux host:

```sh
make
```

Use an explicit compiler:

```sh
make CC=gcc
make CC=clang
```

Explicit aarch64 cross build:

```sh
make cross
make cross TOOLCHAIN_DIR=/opt/arm-gnu-toolchain
```

## Wiring

```text
eth2can0 <-> eth2can4
eth2can1 <-> eth2can2
eth2can3 <-> eth2can5
```

Each pair is one independent CAN FD bus. Use 120 ohm termination at both ends,
keep CANH/CANL polarity correct, power the transceivers, and share ground with
the gateway. Before running `canperf`, load the driver and configure 1M/5M with
`linux/scripts/install_driver.sh`.

## Test model

`canperf` sends and receives on Linux SocketCAN devices. The tested path
includes the Linux `eth2can` driver, Ethernet link, MCXE31B gateway, and
physical CAN FD buses.

`latency` uses the default directions `0->4`, `1->2`, and `3->5`. Each
direction uses one thread and keeps only one CAN frame in flight to measure
end-to-end latency.

`bandwidth` mirrors the harness into six concurrent directions:

```text
0->4  4->0
1->2  2->1
3->5  5->3
```

Each direction uses an independent thread, SocketCAN socket, CAN ID, and
incrementing sequence. The bandwidth test is a controlled rate stress test,
not random traffic. It sends 64-byte CAN FD+BRS frames at a fixed cadence and
keeps at most 16 frames in flight per direction, matching the driver TXC
window depth.

## Latency

```sh
./canperf
./canperf latency
./canperf latency --count 10000
./canperf latency --pair 0:4
./canperf latency --duration 10m
```

Output interpretation:

- The final `RESULT latency` line is the customer conclusion; `PASS` means
  zero application loss with clean counters. A run whose counters cannot be
  read (or whose gateway STATS are stale) is reported `FAIL`, never a false
  pass.
- `total` p50, p99, and p99.9 are the main end-to-end latency numbers.
- p99.9 is also called p999.
- `L1/L2/L3/L4` help localize latency to Linux TX, Ethernet, MCU/CAN, or
  Linux RX.
- `EVIDENCE latency` is intended for reproducible records.
- `counters=clean` means driver and gateway loss, overflow, reject, and
  failure counters did not increase during the run.

## Bidirectional bandwidth

```sh
./canperf bandwidth
./canperf bandwidth --pair 0:4
./canperf bandwidth --count 30000
```

`bandwidth` first sweeps candidate rates, then runs one final confirmation.
For acceptance, only use `RESULT bandwidth`, `MSR`, and `EVIDENCE bandwidth`
from the final confirmation. Do not treat sweep probes as acceptance results.

Result interpretation:

- `RESULT bandwidth: PASS` is the required first condition.
- `MSR = ... fps/pair DELIVERED` is the sustainable frame rate per direction.
- `aggregate` is the sum of all concurrent directions.
- `per CAN bus` shows physical CAN bus utilization.
- `ceiling` indicates whether the observed limit looks CAN-bus-bound or
  gateway/host-path-bound.
- `EVIDENCE bandwidth` is the compact line to copy into reports.

## Common options

```sh
--pair A:B      Select one harness pair; repeat or comma-separate for more pairs
--count N       Frame count for latency; per-step frame count for bandwidth
--duration T    Runtime for latency; per-step runtime for bandwidth
--bitrate R     Nominal bitrate, default 1000000
--dbitrate R    CAN FD data bitrate, default 5000000
--no-setup      Do not configure eth2canN automatically
--help          Show help
```

The customer-facing test scope is CAN FD+BRS. Classic CAN, loopback, CSV
export, and manual sweep/window tuning are not the default acceptance
interfaces.

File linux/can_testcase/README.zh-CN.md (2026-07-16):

# canperf 客户测试工具

[English](README.md)

`canperf` 面向 MCXE31B 桥接器的两类客户验收问题：

- 延迟：`latency`
- 双向最大可持续带宽：`bandwidth`

默认 CAN FD 速率为 1M/5M，并使能 BRS。默认线束为 `0<->4`、`1<->2`、
`3<->5`。

## 编译

在目标 Linux 主机上原生编译：

```sh
make
```

指定编译器：

```sh
make CC=gcc
make CC=clang
```

显式 aarch64 交叉编译：

```sh
make cross
make cross TOOLCHAIN_DIR=/opt/arm-gnu-toolchain
```

## 线束

```text
eth2can0 <-> eth2can4
eth2can1 <-> eth2can2
eth2can3 <-> eth2can5
```

每组是一条独立 CAN FD 总线。总线两端各使用 120 ohm 终端，CANH/CANL 极性
正确，收发器供电正常，并与网关共地。运行 `canperf` 前，请先使用
`linux/scripts/install_driver.sh` 加载驱动并配置 1M/5M。

## 测试模型

`canperf` 在 Linux SocketCAN 设备上发包和收包。测试路径包含 Linux
`eth2can` 驱动、Ethernet 链路、MCXE31B 网关和物理 CAN FD 总线。

`latency` 默认使用 `0->4`、`1->2`、`3->5` 三个方向。每个方向一个线程，
一次只保留一帧在途，用于测量端到端延迟。

`bandwidth` 将默认线束镜像成六个并发方向：

```text
0->4  4->0
1->2  2->1
3->5  5->3
```

每个方向使用独立线程、SocketCAN socket、CAN ID 和递增 sequence。带宽测试
是受控速率压力测试，不是随机流量。它按固定节奏发送 64 字节 CAN FD+BRS
帧，每个方向最多保持 16 帧在途，与驱动 TXC window 深度一致。

## 延迟测试

```sh
./canperf
./canperf latency
./canperf latency --count 10000
./canperf latency --pair 0:4
./canperf latency --duration 10m
```

输出解读：

- 最终 `RESULT latency` 行是客户结论；`PASS` 表示本次运行零丢帧且计数器
  clean。计数器不可读、或网关 STATS 过期，会判 `FAIL`，不会误报 PASS。
- `total` 的 p50、p99 和 p99.9 是主要端到端延迟指标。
- p99.9 也称为 p999。
- `L1/L2/L3/L4` 用于定位延迟来自 Linux TX、Ethernet、MCU/CAN 或 Linux RX。
- `EVIDENCE latency` 用于保存可复验记录。
- `counters=clean` 表示驱动和网关的丢帧、溢出、拒绝、失败等计数器未增长。

## 双向带宽测试

```sh
./canperf bandwidth
./canperf bandwidth --pair 0:4
./canperf bandwidth --count 30000
```

`bandwidth` 会先搜索候选速率，再执行一次 final confirmation。客户验收只使用
final confirmation 的 `RESULT bandwidth`、`MSR` 和 `EVIDENCE bandwidth`；
不要把 sweep 试探阶段当作验收结果。

结果解读：

- `RESULT bandwidth: PASS` 是首要条件。
- `MSR = ... fps/pair DELIVERED` 是每个方向的可持续帧率。
- `aggregate` 是所有并发方向的合计帧率。
- `per CAN bus` 表示物理 CAN 总线利用率。
- `ceiling` 提示当前限制更像 CAN 总线受限，还是网关/主机路径受限。
- `EVIDENCE bandwidth` 是可复制到报告里的简洁证据行。

## 常用参数

```sh
--pair A:B      指定一组线束；可重复或逗号分隔指定多组
--count N       latency 的帧数；bandwidth 的每步帧数
--duration T    latency 的运行时间；bandwidth 的每步运行时间
--bitrate R     仲裁相位速率，默认 1000000
--dbitrate R    CAN FD 数据相位速率，默认 5000000
--no-setup      不自动配置 eth2canN
--help          查看帮助
```

客户测试范围是 CAN FD+BRS。classic CAN、loopback、CSV 导出和手动
sweep/window 调参不作为默认验收接口。

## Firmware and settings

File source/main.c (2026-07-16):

/*
 * main.c - E2CF gateway firmware, bare-metal superloop (MCXE31B)
 *
 * Copyright 2026 NXP
 * Author: Ken Li <ken.li@nxp.com>
 *
 * SPDX-License-Identifier: BSD-3-Clause
 *
 * Architecture (design doc 03 §2.2): the data plane lives in tiered NVIC
 * interrupts (CAN RX/TXC prio 1, EMAC RX prio 2); the superloop only runs
 * non-deadline work - T_agg flush checks, HB/EVT/TIME ticks, error polling,
 * link supervision, statistics and deferred log draining.
 */
#include <stdint.h>

#include "board.h"
#include "can_hw.h"
#include "dbg_log.h"
#include "e2cf_config.h"
#include "e2cf_core.h"
#include "e2cf_proto.h"
#include "eth_raw.h"
#include "fsl_debug_console.h"
#include "gw_time.h"
#include "status_led.h"

static volatile uint32_t s_ms;

/*
 * 1 ms tick: advance the coarse millisecond counter and run the DWT wrap
 * tracker.
 */
void SysTick_Handler(void)
{
    s_ms++;
    gw_time_track_wrap();
}

/* ---- fault logging (kept from the donor project: prints stacked regs) ---- */

static void fault_log_and_halt(const char *name, const uint32_t *stacked, uint32_t exc_return)
{
    PRINTF("\r\nFault: %s\r\n", name);
    if (stacked != NULL)
    {
        PRINTF("  r0=%08lx r1=%08lx r2=%08lx r3=%08lx\r\n",
               (unsigned long)stacked[0], (unsigned long)stacked[1],
               (unsigned long)stacked[2], (unsigned long)stacked[3]);
        PRINTF("  r12=%08lx lr=%08lx pc=%08lx xpsr=%08lx\r\n",
               (unsigned long)stacked[4], (unsigned long)stacked[5],
               (unsigned long)stacked[6], (unsigned long)stacked[7]);
    }
    PRINTF("  exc_return=%08lx CFSR=%08lx HFSR=%08lx BFAR=%08lx\r\n",
           (unsigned long)exc_return, (unsigned long)SCB->CFSR,
           (unsigned long)SCB->HFSR, (unsigned long)SCB->BFAR);
    status_led_fault();
    while (1)
    {
        __asm volatile("nop");
    }
}

/* C-level HardFault sink: print the stacked register frame and halt. */
static void fault_log_hardfault(uint32_t *stacked, uint32_t exc_return) __attribute__((used));
static void fault_log_hardfault(uint32_t *stacked, uint32_t exc_return)
{
    fault_log_and_halt("HardFault", stacked, exc_return);
}

/*
 * Naked entry: select MSP/PSP from EXC_RETURN bit 2 and branch to the C sink.
 */
void HardFault_Handler(void) __attribute__((naked));
void HardFault_Handler(void)
{
    __asm volatile(
        "tst lr, #4\n"
        "ite eq\n"
        "mrseq r0, msp\n"
        "mrsne r0, psp\n"
        "mov r1, lr\n"
        "b fault_log_hardfault\n");
}

/* ---- main ----------------------------------------------------------------*/

/*
 * Board/eth/can/core bring-up followed by the superloop: data-plane
 * housekeeping every iteration, error polling at 10 ms, link polling at 100
 * ms, deferred log drain and debug console.
 */
int main(void)
{
    uint32_t last_err_poll_ms = 0U;
    uint32_t last_link_poll_ms = 0U;
#if E2CF_STATS_PERIOD_MS != 0U
    uint32_t last_stats_ms = 0U;
#endif

    BOARD_InitHardware();
    status_led_init();
    gw_time_init();
    dbg_log_init();

    SysTick_Config(SystemCoreClock / 1000U);
    NVIC_SetPriority(SysTick_IRQn, E2CF_IRQPRIO_SYSTICK);

    PRINTF("\r\n=============================================\r\n");
    PRINTF("  E2CF gateway  -  MCXE31B  (fw %08lx)\r\n", (unsigned long)E2CF_FW_VERSION);
    PRINTF("  build " __DATE__ " " __TIME__ "\r\n");
    PRINTF("  proto v%u  ethertype 0x%04x  win %u  T_agg %uus\r\n",
           E2CF_VERSION, E2CF_ETHERTYPE, E2CF_WIN_DEPTH, E2CF_T_AGG_US);
    PRINTF("  chan mask 0x%02x  autostart %u  loopback %u\r\n",
           E2CF_ACTIVE_CHAN_MASK, E2CF_AUTOSTART_CHANNELS, E2CF_AUTOSTART_LOOPBACK);
    PRINTF("  dbg: keys 0-5=level m=mask s=stats p=profile ?=help\r\n");
    PRINTF("=============================================\r\n\r\n");

    /* Core aggregation state (face=-1 sentinels) must be reset BEFORE any
     * data-plane IRQ or CAN autostart can fire an upcall against it. */
    (void)e2cf_core_init();

    if (!eth_raw_init())
    {
        PRINTF("FATAL: ethernet init failed\r\n");
        status_led_fault();
        while (1) {}
    }
    if (!can_hw_init())
    {
        PRINTF("FATAL: can init failed\r\n");
        status_led_fault();
        while (1) {}
    }

    while (1)
    {
        uint32_t ms = s_ms;

        /* Data-plane housekeeping with sub-us resolution. */
        e2cf_core_poll();
        status_led_poll(ms);

        /* 10 ms: CAN error/fault supervision + stuck-TX watchdog. */
        if ((ms - last_err_poll_ms) >= 10U)
        {
            last_err_poll_ms = ms;
            can_hw_poll_errors();
        }

        /* 100 ms: PHY link state. */
        if ((ms - last_link_poll_ms) >= 100U)
        {
            last_link_poll_ms = ms;
            eth_raw_poll_link();
        }

        /* Deferred log drain (bounded) + runtime debug console. */
        dbg_log_drain(256U);
        if (dbg_log_console_poll())
        {
            /* 's' pressed: dump everything now. */
            eth_raw_dump_stats();
            can_hw_dump_stats();
            e2cf_core_dump_stats();
        }

#if E2CF_STATS_PERIOD_MS != 0U
        if ((ms - last_stats_ms) >= E2CF_STATS_PERIOD_MS)
        {
            last_stats_ms = ms;
            eth_raw_dump_stats();
            can_hw_dump_stats();
            e2cf_core_dump_stats();
        }
#endif
    }
}

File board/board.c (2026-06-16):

/*
 * Copyright 2025, 2026 NXP
 * Author: Ken Li <ken.li@nxp.com>
 *
 * SPDX-License-Identifier: BSD-3-Clause
 */
#include "board.h"
#include "fsl_debug_console.h"

/*******************************************************************************
 * Definitions
 ******************************************************************************/

/*******************************************************************************
 * Variables
 ******************************************************************************/

/*******************************************************************************
 * Prototypes
 ******************************************************************************/

/*******************************************************************************
 * Code
 ******************************************************************************/
void BOARD_ConfigMPU(void)
{
#if defined(SDK_SRAM_NONCACHE_SECTION) /* If Non-cacheable section is located in SRAM. */
#if defined(__CC_ARM) || defined(__ARMCC_VERSION)
    extern uint32_t Image$$RW_m_ncache$$Base[];
    /* RW_m_ncache_unused is a auxiliary region which is used to get the whole size of noncache section */
    extern uint32_t Image$$RW_m_ncache_unused$$Base[];
    extern uint32_t Image$$RW_m_ncache_unused$$ZI$$Limit[];
    extern uint32_t Image$$RW_m_ncache_aux$$Base[];
    uint32_t nonCacheStart = (uint32_t)Image$$RW_m_ncache$$Base;
    uint32_t nonCacheSize  = ((uint32_t)Image$$RW_m_ncache_unused$$Base == nonCacheStart) ?
                                 0 :
                                 ((uint32_t)Image$$RW_m_ncache_unused$$ZI$$Limit - nonCacheStart);
#elif defined(__MCUXPRESSO)
    extern uint32_t __base_NCACHE_REGION;
    extern uint32_t __top_NCACHE_REGION;
    uint32_t nonCacheStart = (uint32_t)(&__base_NCACHE_REGION);
    uint32_t nonCacheSize  = (uint32_t)(&__top_NCACHE_REGION) - nonCacheStart;
#elif defined(__ICCARM__) || defined(__GNUC__)
    extern uint32_t __NCACHE_REGION_START[];
    extern uint32_t __NCACHE_REGION_SIZE[];
    uint32_t nonCacheStart = (uint32_t)__NCACHE_REGION_START;
    uint32_t nonCacheSize  = (uint32_t)__NCACHE_REGION_SIZE;
#endif

    volatile uint32_t i;
#endif

   /* Disable I cache and D cache */
    if (SCB_CCR_IC_Msk == (SCB_CCR_IC_Msk & SCB->CCR))
    {
        SCB_DisableICache();
    }
    if (SCB_CCR_DC_Msk == (SCB_CCR_DC_Msk & SCB->CCR))
    {
        SCB_DisableDCache();
    }

    /* Disable MPU */
    ARM_MPU_Disable();

    /* clang-format off */

    /* MPU configure:
     * Use ARM_MPU_RASR(DisableExec, AccessPermission, TypeExtField, IsShareable, IsCacheable, IsBufferable, SubRegionDisable, Size)
     * API in mpu_armv7.h.
     * param DisableExec       Instruction access (XN) disable bit,0=instruction fetches enabled, 1=instruction fetches disabled.
     * param AccessPermission  Data access permissions, allows you to configure read/write access for User and Privileged mode.
     *                         Use MACROS defined in mpu_armv7.h:
     *                         ARM_MPU_AP_NONE/ARM_MPU_AP_PRIV/ARM_MPU_AP_URO/ARM_MPU_AP_FULL/ARM_MPU_AP_PRO/ARM_MPU_AP_RO
     *
     * Combine TypeExtField/IsShareable/IsCacheable/IsBufferable to configure MPU memory access attributes.
     *  TypeExtField  IsShareable  IsCacheable  IsBufferable   Memory Attribute    Shareability        Cache
     *     0             x           0           0             Strongly Ordered    shareable
     *     0             x           0           1              Device             shareable
     *     0             0           1           0              Normal             not shareable   Outer and inner write
     *                                                                                             through no write allocate
     *     0             0           1           1              Normal             not shareable   Outer and inner write
     *                                                                                             back no write allocate
     *     0             1           1           0              Normal             shareable       Outer and inner write
     *                                                                                             through no write allocate
     *     0             1           1           1              Normal             shareable       Outer and inner write
     *                                                                                             back no write allocate
     *     1             0           0           0              Normal             not shareable   outer and inner
     *                                                                                             noncache
     *     1             1           0           0              Normal             shareable       outer and inner
     *                                                                                             noncache
     *     1             0           1           1              Normal             not shareable   outer and inner write
     *                                                                                             back write/read acllocate
     *     1             1           1           1              Normal             shareable       outer and inner write
     *                                                                                             back write/read acllocate
     *     2             x           0           0              Device             not shareable
     *   Above are normal use settings, if your want to see more details or want to config different inner/outer cache
     * policy, please refer to Table 4-55 /4-56 in arm cortex-M7 generic user guide <dui0646b_cortex_m7_dgug.pdf>
     *
     * param SubRegionDisable  Sub-region disable field. 0=sub-region is enabled, 1=sub-region is disabled.
     * param Size              Region size of the region to be configured. use ARM_MPU_REGION_SIZE_xxx MACRO in mpu_armv7.h.
     */

    /* clang-format on */

    /*
     * Add default region to deny access to whole address space to workaround speculative prefetch.
     * Refer to Arm errata 1013783-B for more details.
     */
    /* Region 0 setting: Instruction access disabled, No data access permission. */
    MPU->RBAR = ARM_MPU_RBAR(0, 0x00000000U);
    MPU->RASR = ARM_MPU_RASR(1, ARM_MPU_AP_NONE, 0, 0, 0, 0, 0, ARM_MPU_REGION_SIZE_4GB);

    /* Region 1 setting: Memory with Normal type, not shareable, outer/inner noncache, ITCM */
    MPU->RBAR = ARM_MPU_RBAR(1, 0x00000000U);
    MPU->RASR = ARM_MPU_RASR(0, ARM_MPU_AP_FULL, 1, 0, 0, 0, 0, ARM_MPU_REGION_SIZE_32KB);
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

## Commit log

2026-07-02 Refine E2CF delivery flow and status indicators
2026-07-16 e2cf: log-drain fix, DATA-trailer fix, canperf fail-closed hardening
    Board firmware (MCU):
    - dbg_log_drain now uses a non-blocking, TDRE-gated LPUART write instead of the
    blocking DbgConsole_Putchar, so a debug-log burst no longer stalls the
    superloop and delays the T_agg uplink flush (board uplink-latency worst case
    ~6ms -> ~320us).
    Linux driver (eth2can):
    - e2cf_rx_data locates the DATA eth-egress trailer by walking the records (new
    e2cf_data_layout.h) instead of reading the tail of the payload. The old code
    read the trailer out of the MCU 60-byte min-frame zero padding on
    small/single-record frames and silently dropped the hardware timestamp used
    for the MCU-residency (Y-X)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
    [dbg_log.c, eth2can.c]
2026-07-16 Fix boot-window init-order race and stuck-TX watchdog false abort
    e2cf_core_init() ran after eth_raw_init()/can_hw_init(), so the EMAC and CAN data-plane IRQs (plus autostart channels) went live before the core aggregation state was reset. The agg_t.face closed sentinel is -1, but the BSS-zero value 0 passes the face-open test (face >= 0), so a boot-window RX upcall would append a record into an unallocated, header-less face 0. Move e2cf_core_init() ahead of the peripheral inits, and give s_agg_data/s_agg_txc a static face=-1 initializer so the closed state holds from reset regardless of bring-up order.
    The stuck-TX watchdog in can_hw_poll_errors() re-checked only ch->tx_busy inside the PRI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
    [e2cf_core.c, main.c]
